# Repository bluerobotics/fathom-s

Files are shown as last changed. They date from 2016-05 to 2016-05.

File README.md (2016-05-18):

# Fathom-S

The Fathom Tether Boards are part of Blue Robotics' *Fathom Tether*. These boards provide interfaces and functionality for the communication methods used with the tether. With the Fathom tether, it is quick and easy to get up and running and interface with your ROV or other application.

The schematic and board layout are designed in EagleCAD.

Please see the [Blue Robotics Fathom-S Documentation Page](http://docs.bluerobotics.com/fathom-s/) for more information.

## License

The Fathom Serial Hardware Design is released under the MIT License.

## Revision History

0.0 - Under development. Not fully functional.

0.1 - Second prototype. Not fully functional.

0.2 - Third prototype. First beta release - works great.

0.3 - Rev5, incorporating big changes from beta tests.

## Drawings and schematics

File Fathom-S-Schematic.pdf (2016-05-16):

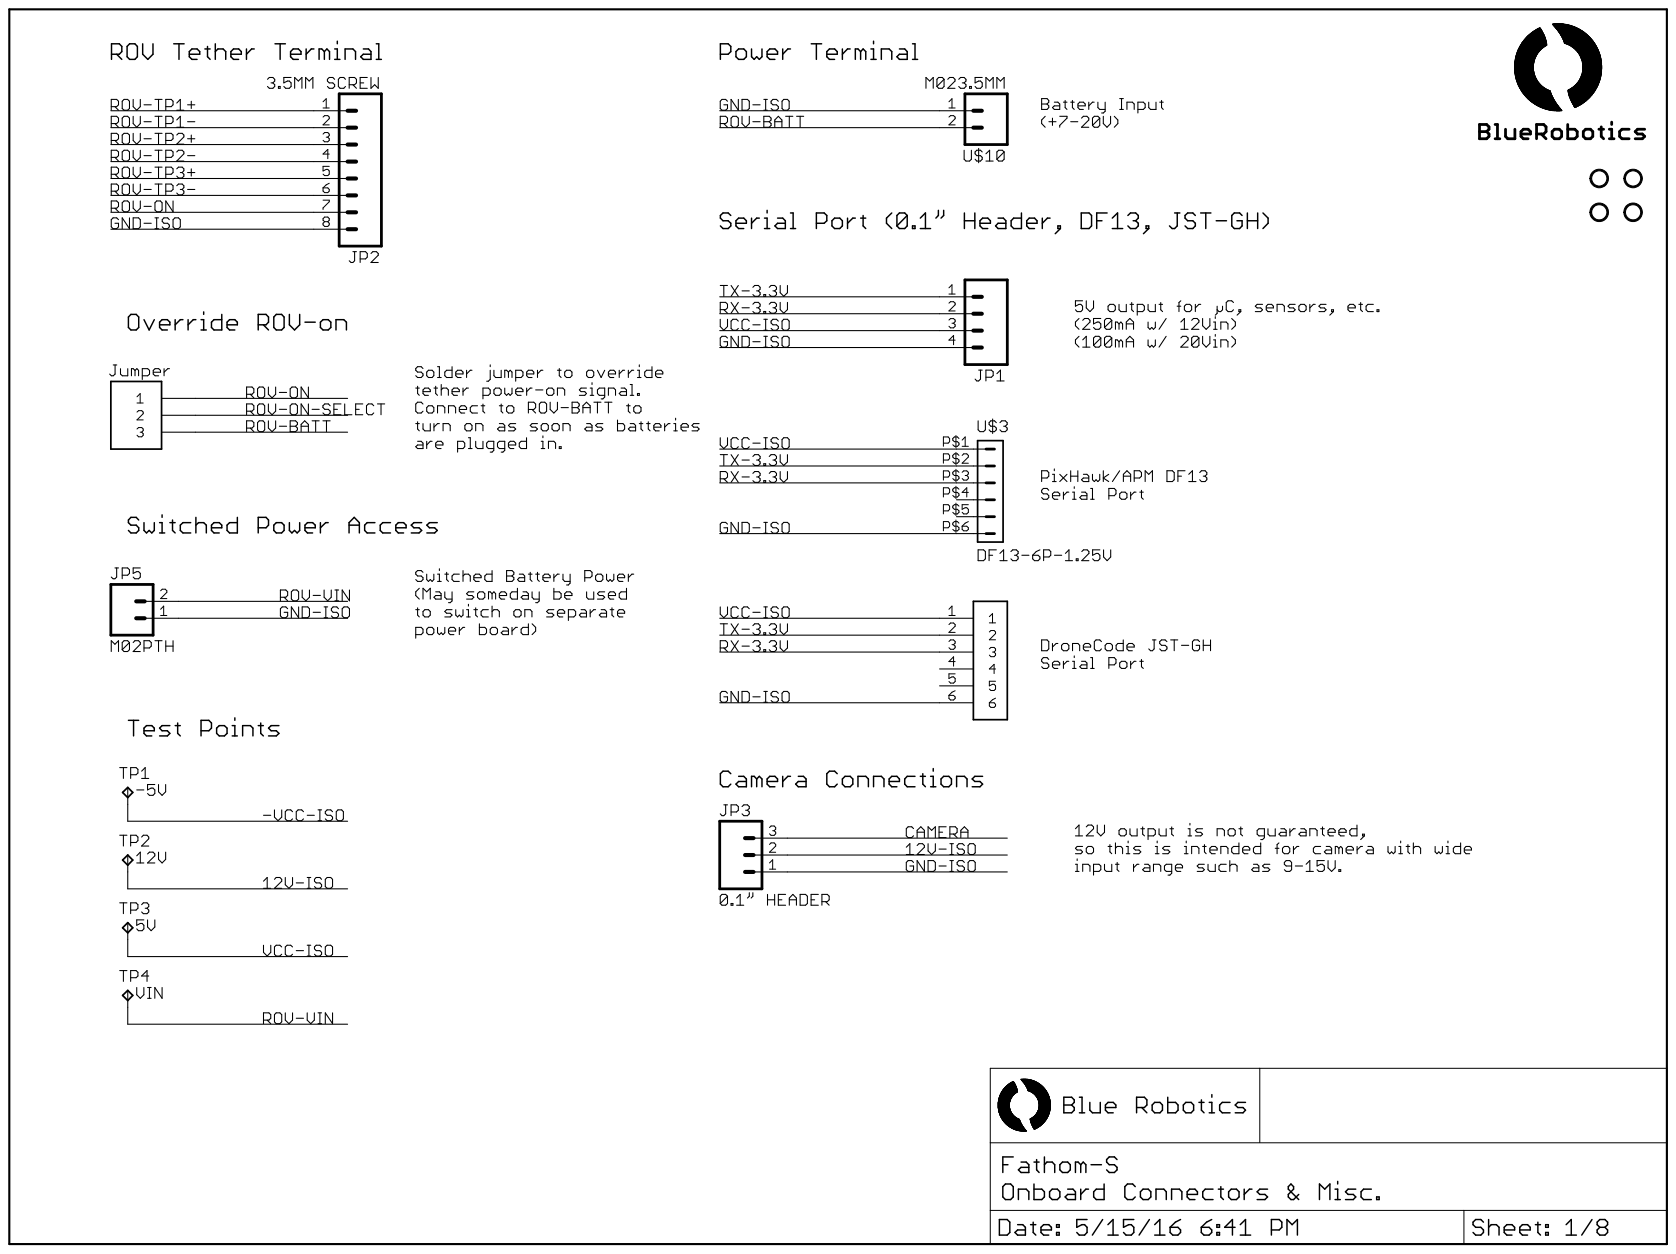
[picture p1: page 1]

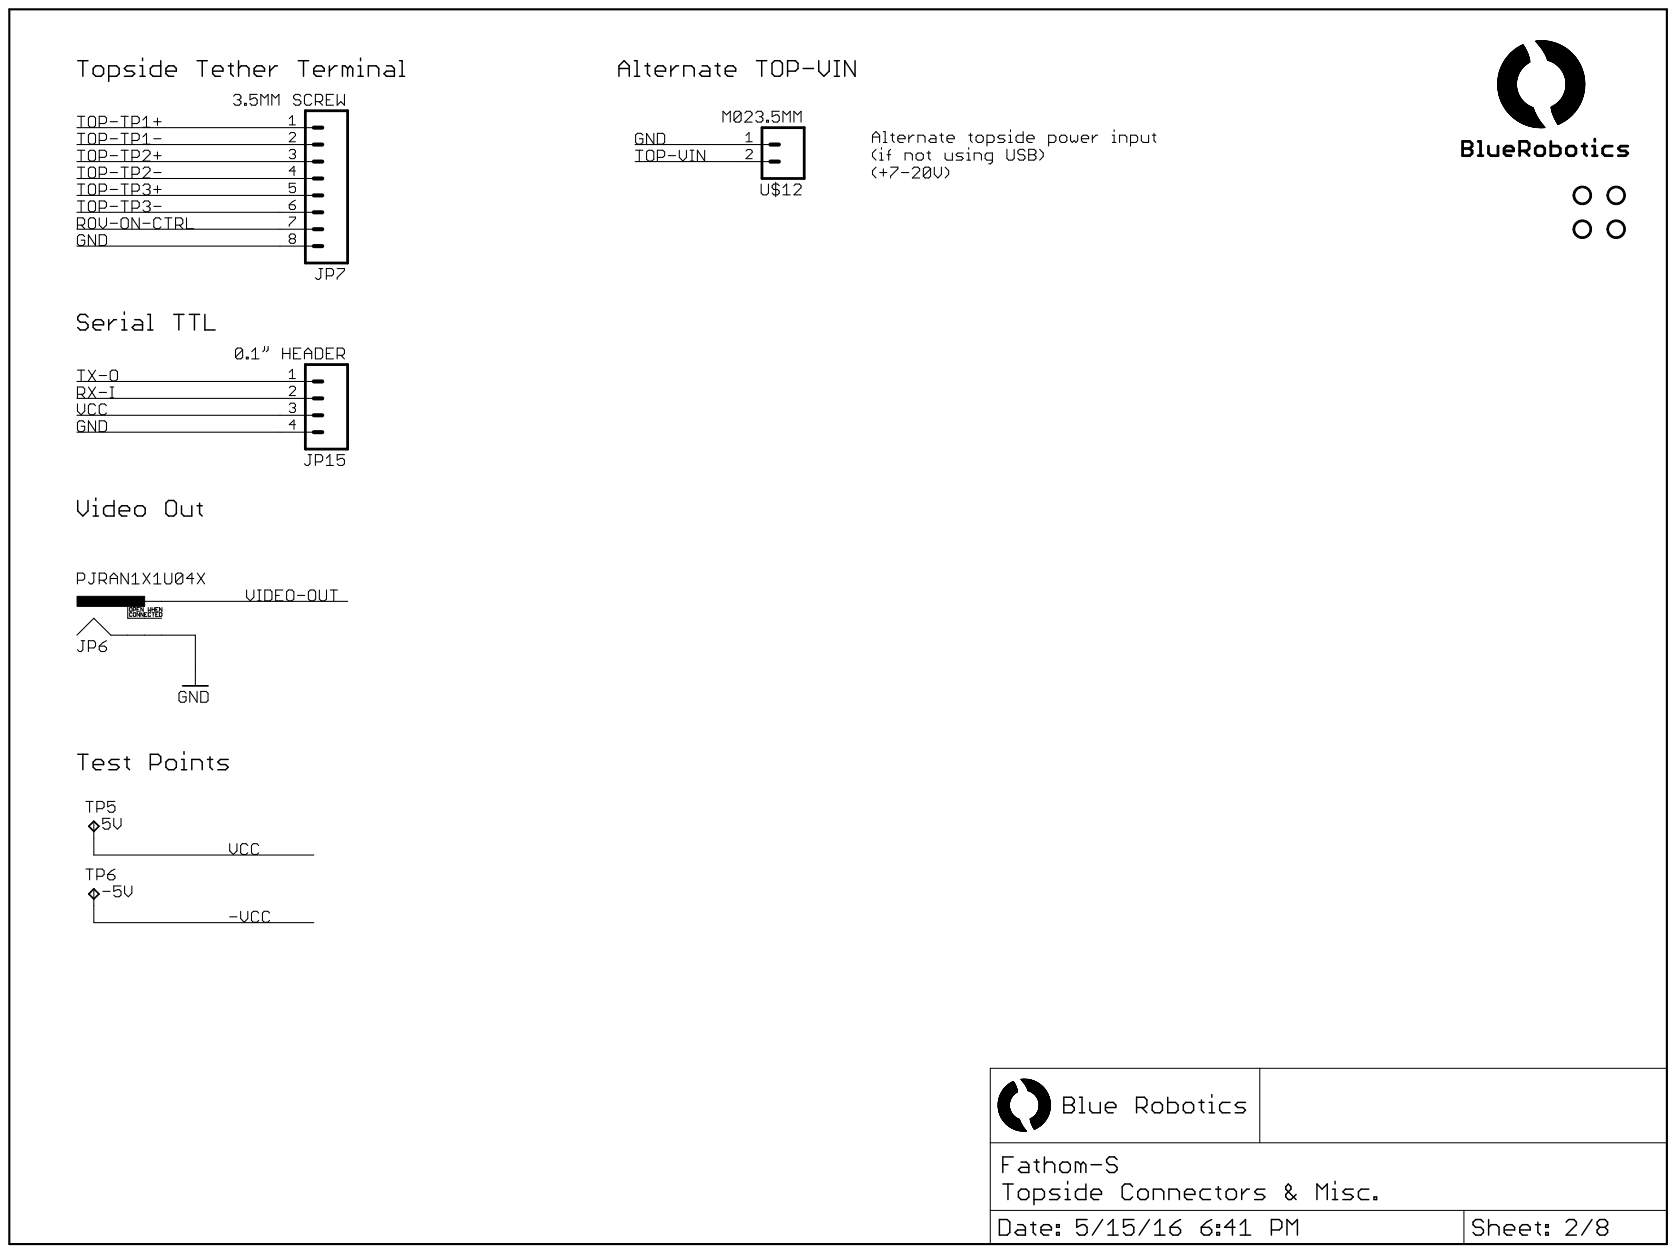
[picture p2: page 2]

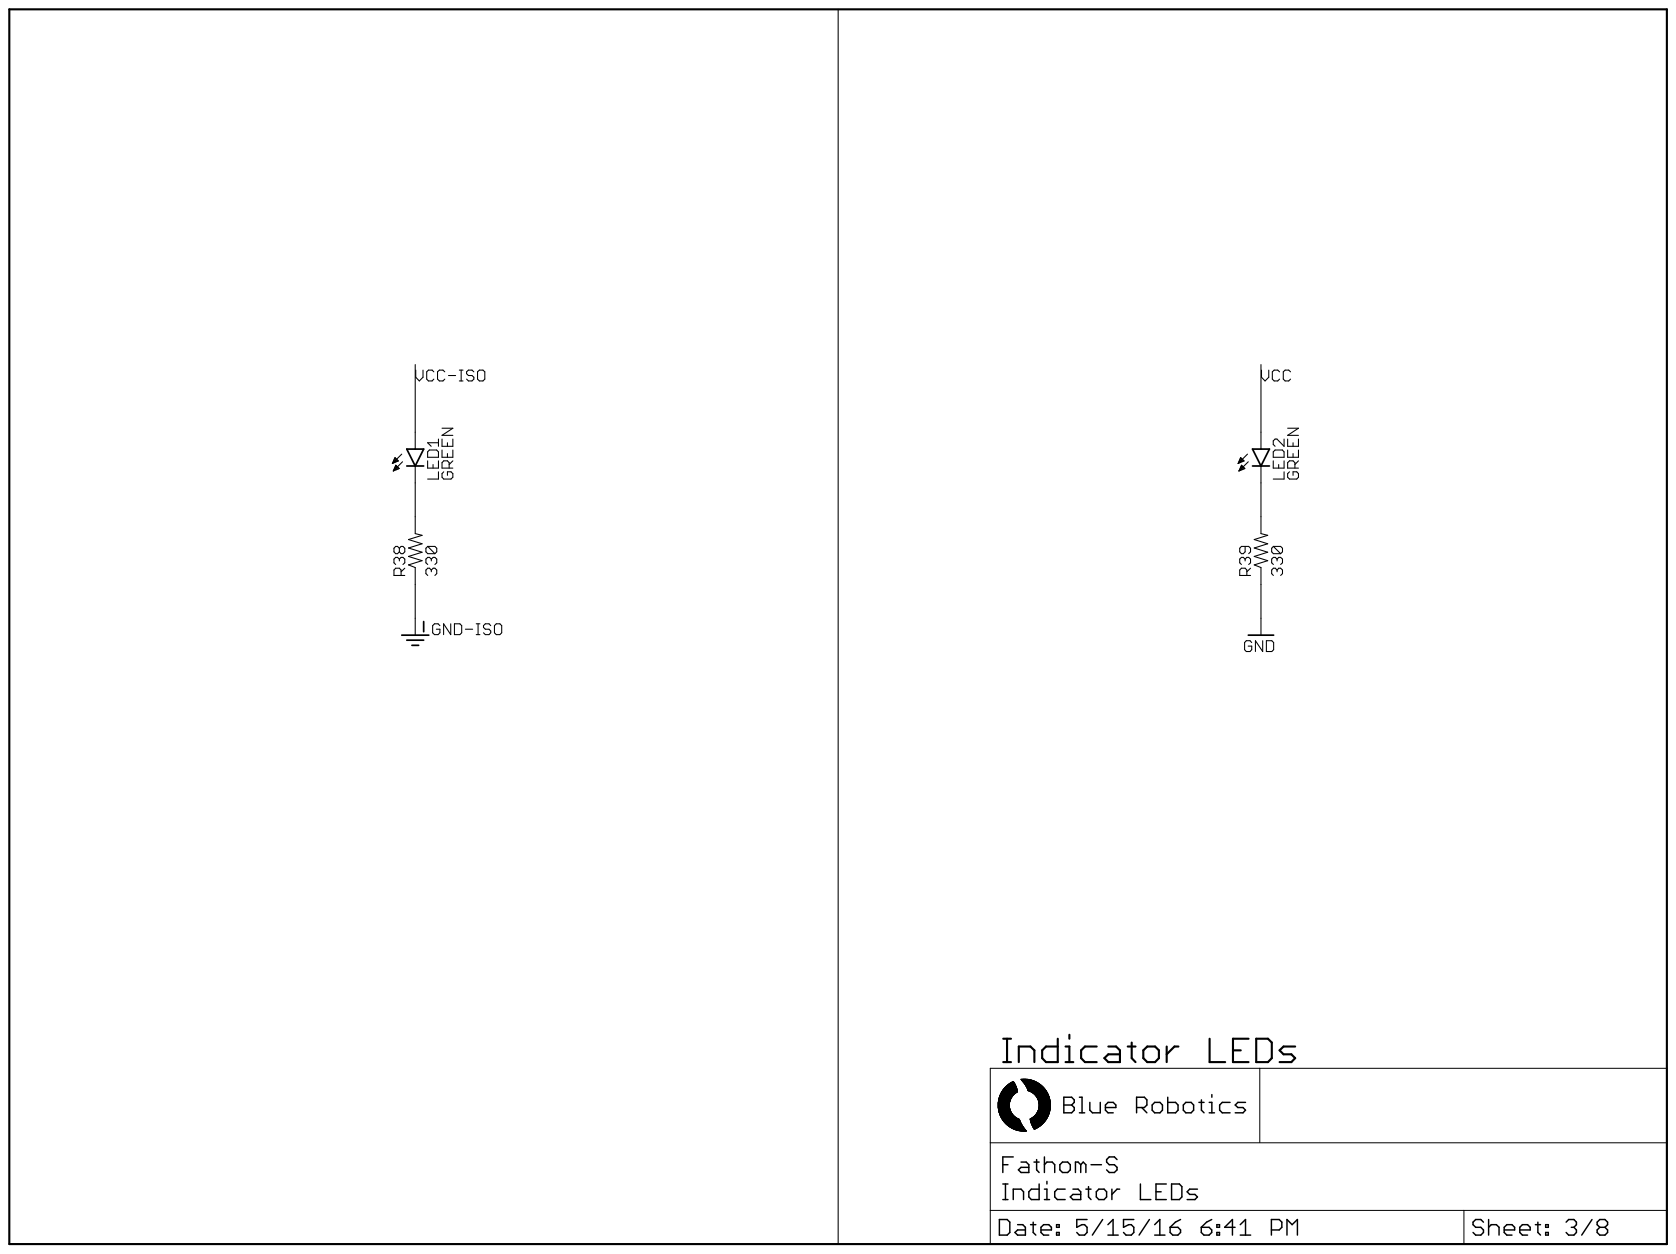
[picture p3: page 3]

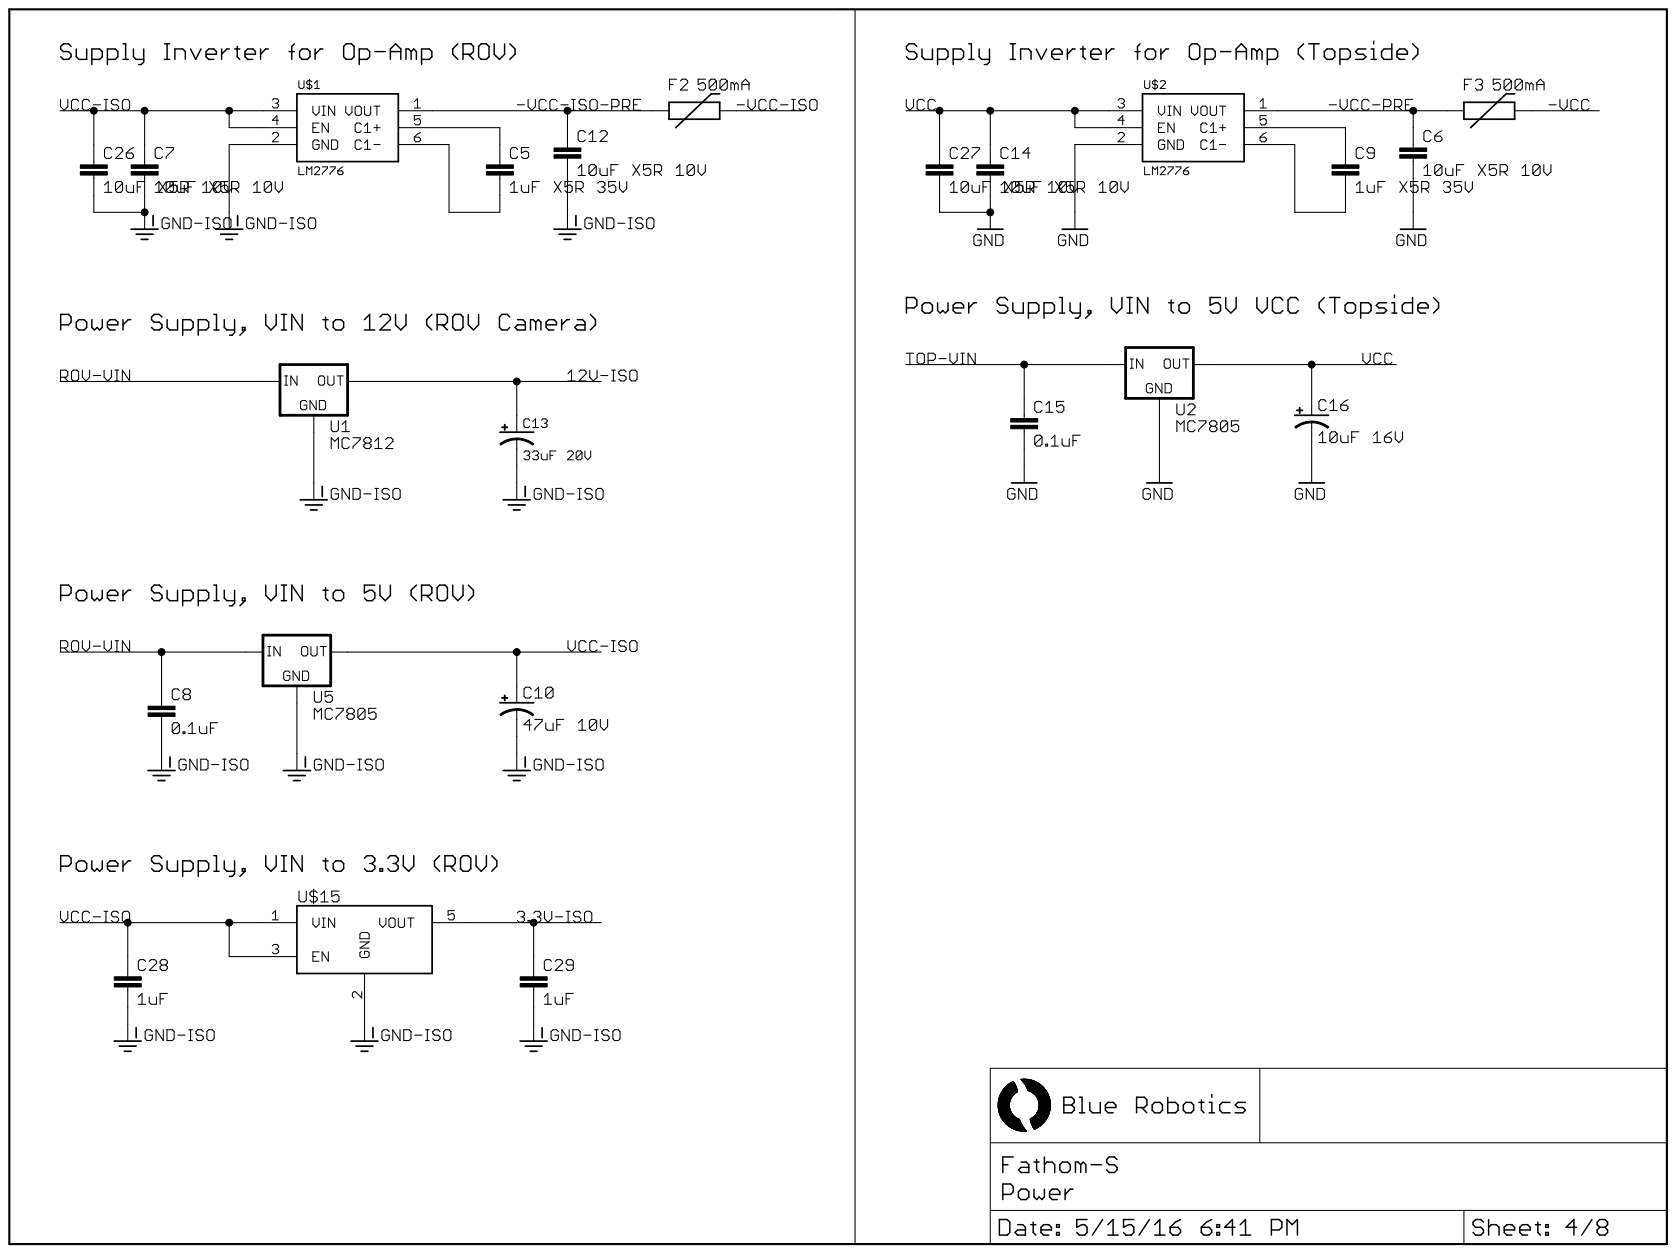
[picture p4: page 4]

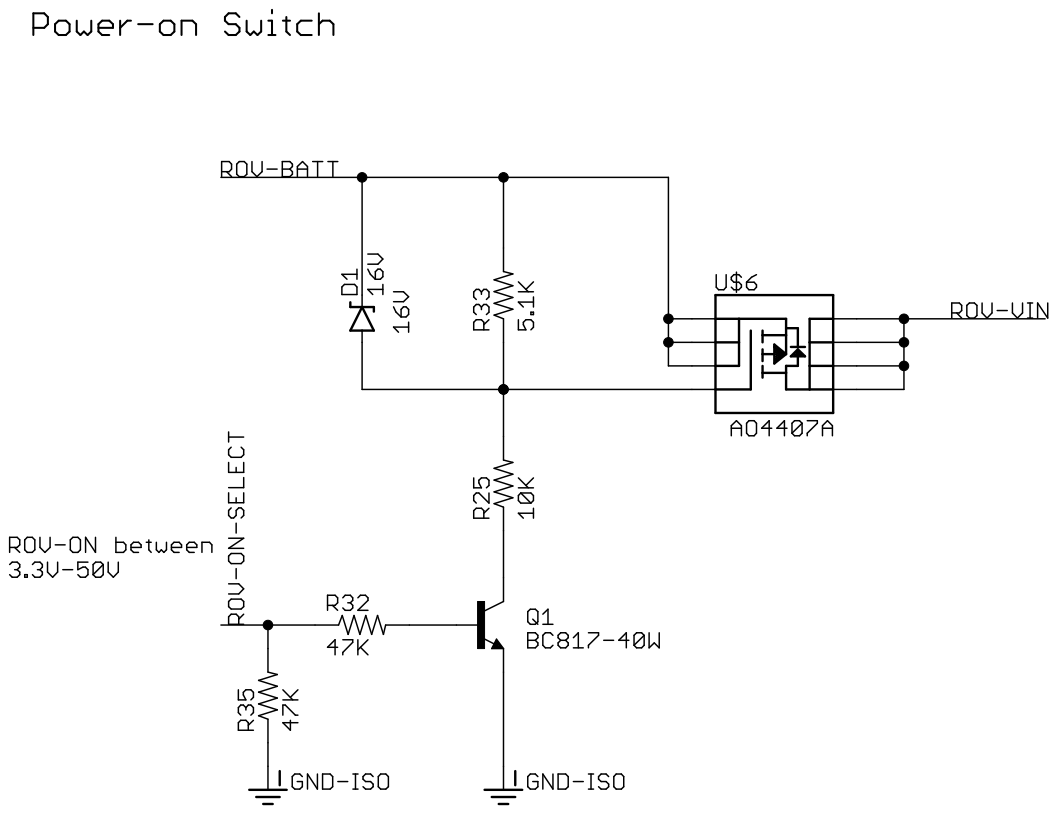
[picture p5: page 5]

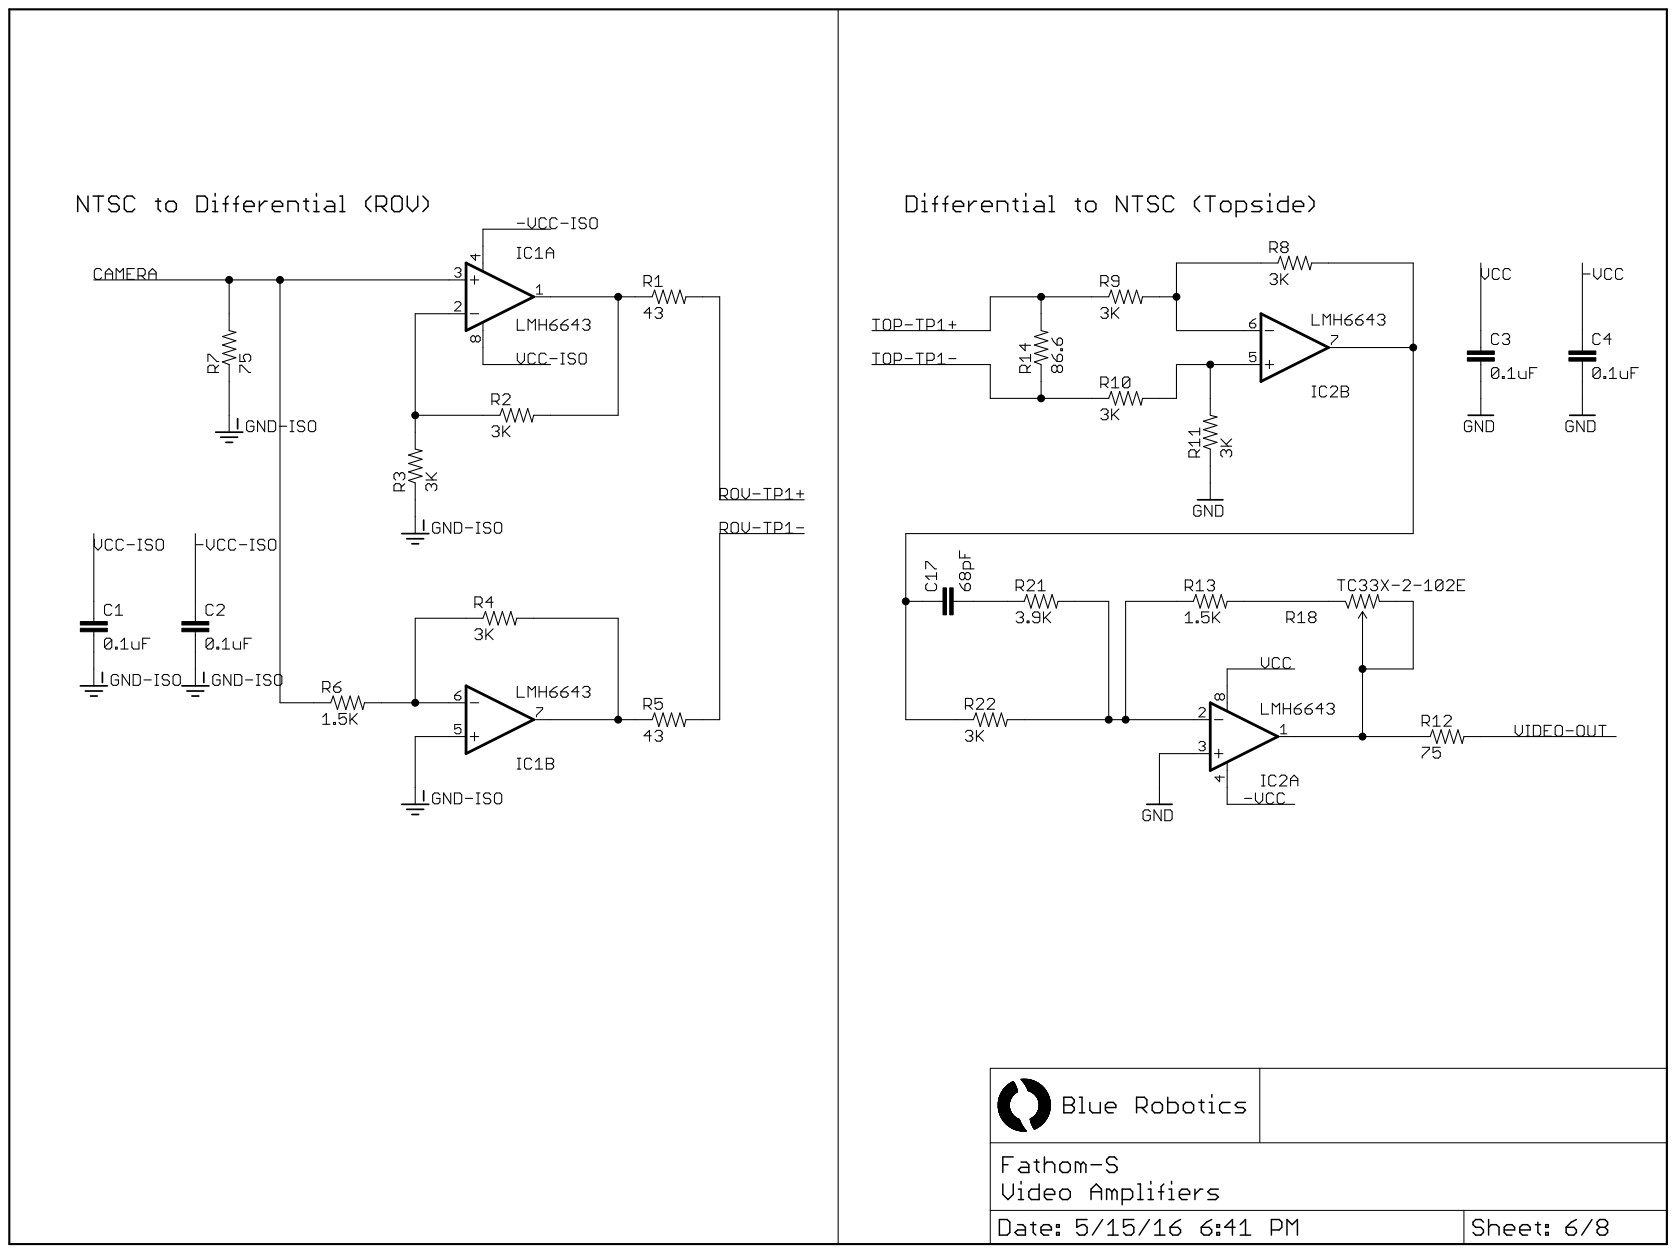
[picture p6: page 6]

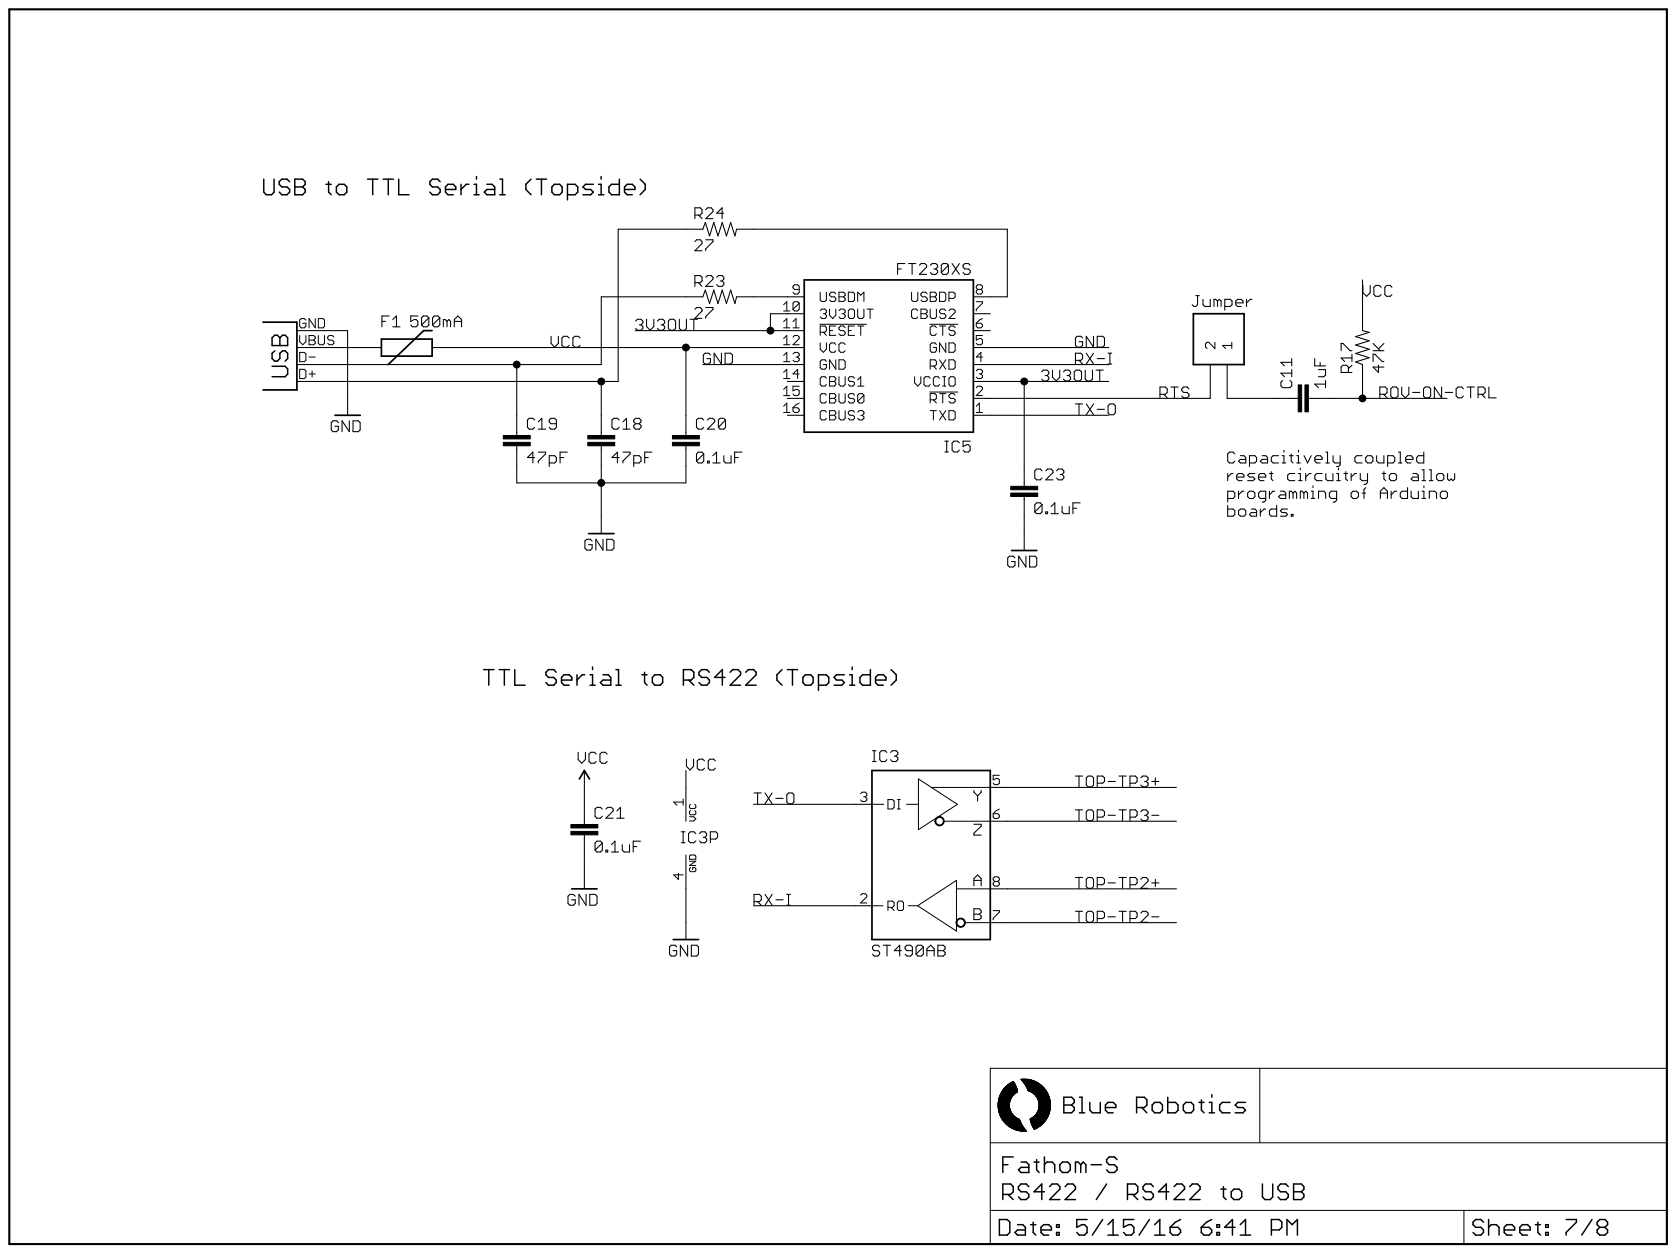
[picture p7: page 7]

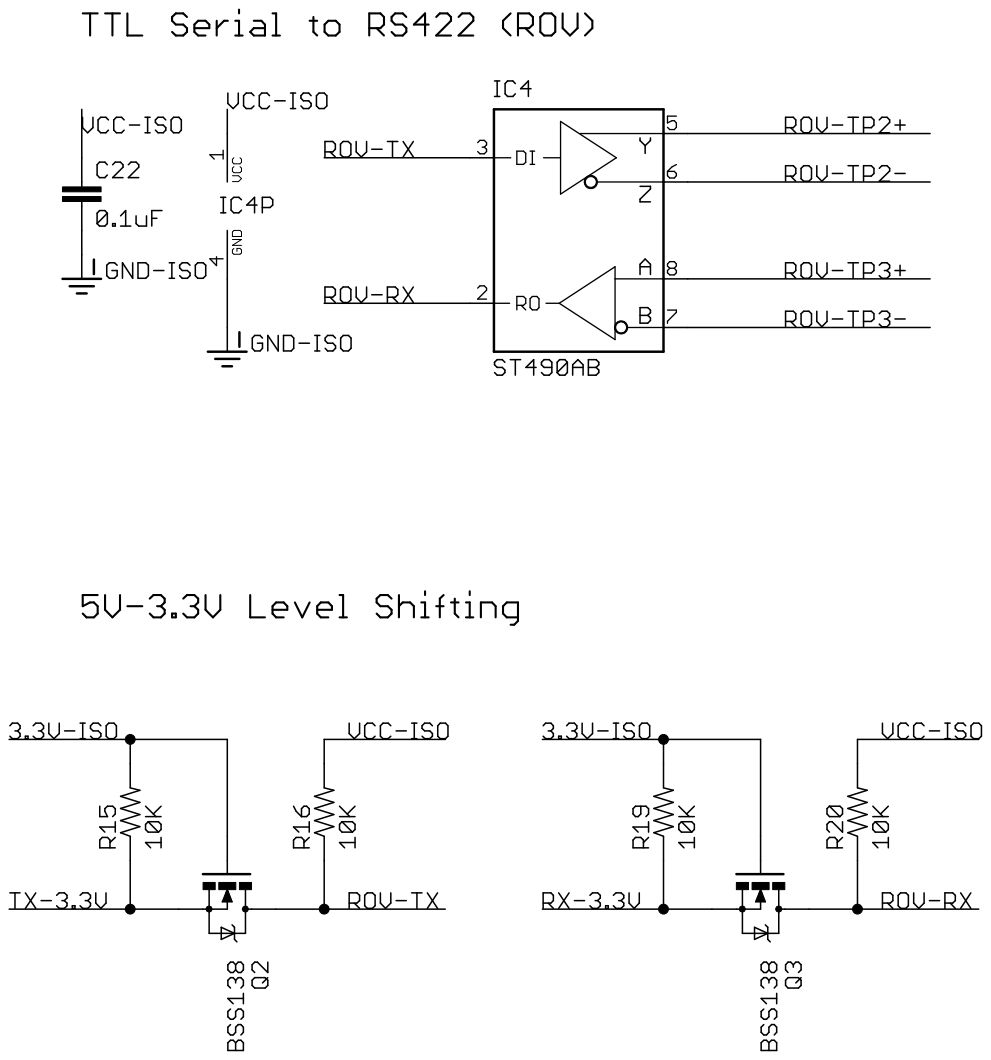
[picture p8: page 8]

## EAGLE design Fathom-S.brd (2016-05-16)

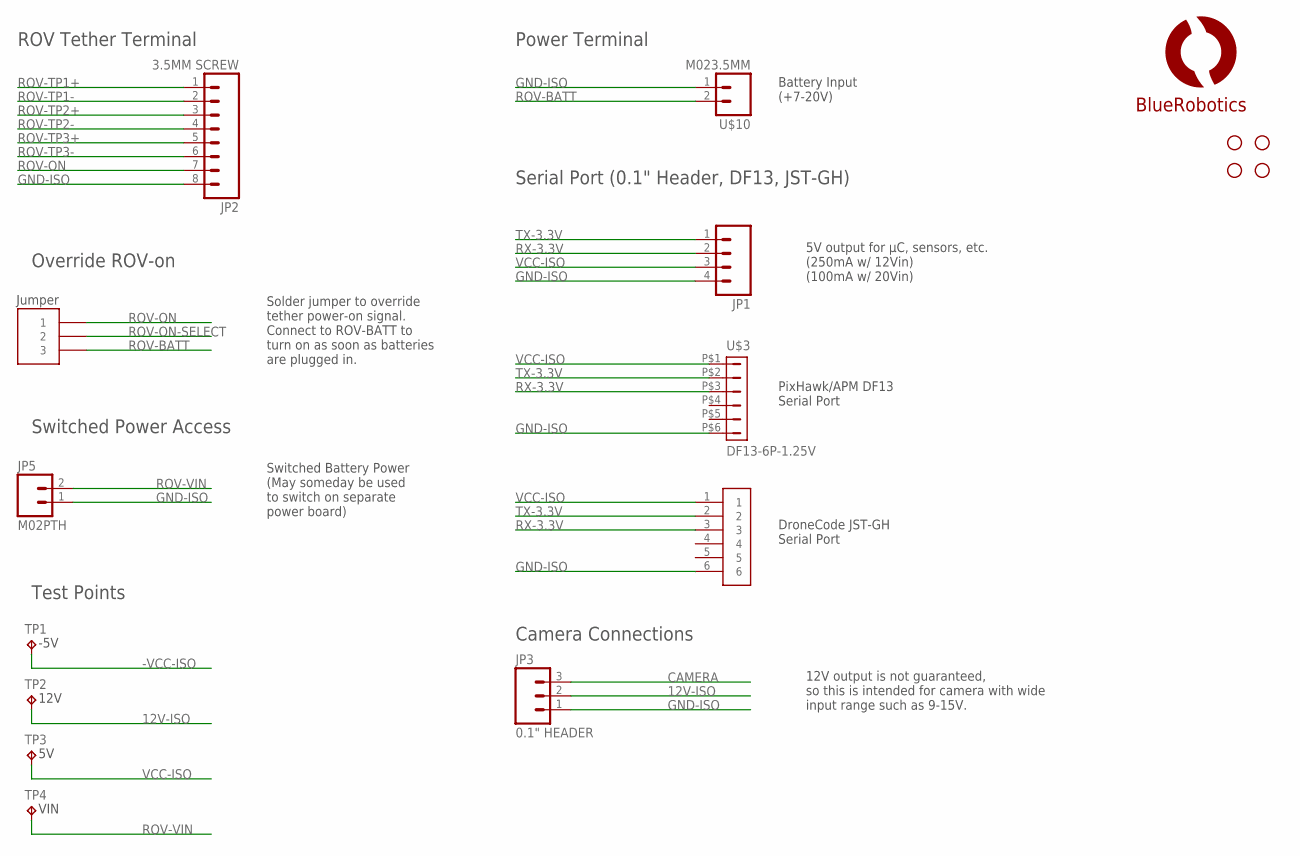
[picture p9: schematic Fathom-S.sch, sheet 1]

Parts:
JP1: M04PTH; 1X04
JP2: 3.5MM SCREW; SCREWTERMINAL-3.5MM-8
JP3: 0.1" HEADER; 1X03
JP5: M02PTH; 1X02
STANDOFF1, STANDOFF2, STANDOFF3, STANDOFF4: STAND-OFF
TP1: -5V; B1,27
TP2: 12V; B1,27
TP3: 5V; B1,27
TP4: VIN; B1,27
U$3: DF13-6P-1.25V; DF13C-6P-1.25V
U$4: LOGOFULL-M; BR-FULL-LOGO-MEDIUM
U$10: M023.5MM; SCREWTERMINAL-3.5MM-2
U$11: JST-GH-6TOP-ENTRY; JST-GH-TOP-6
U$13: HEADER-33MM; HEADER-2MM-3POS

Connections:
12V-ISO: JP3.2, TP2.TP; also elsewhere on the board
-VCC-ISO: TP1.TP; also elsewhere on the board
CAMERA: JP3.3; also elsewhere on the board
GND-ISO: JP1.4, JP2.8, JP3.1, JP5.1, U$3.P$6 (6), U$10.1, U$11.6; also elsewhere on the board
ROV-BATT: U$10.2, U$13.P$3 (3); also elsewhere on the board
ROV-ON: JP2.7, U$13.P$1 (1)
ROV-ON-SELECT: U$13.P$2 (2); also elsewhere on the board
ROV-TP1+: JP2.1; also elsewhere on the board
ROV-TP1-: JP2.2; also elsewhere on the board
ROV-TP2+: JP2.3; also elsewhere on the board
ROV-TP2-: JP2.4; also elsewhere on the board
ROV-TP3+: JP2.5; also elsewhere on the board
ROV-TP3-: JP2.6; also elsewhere on the board
ROV-VIN: JP5.2, TP4.TP; also elsewhere on the board
RX-3.3V: JP1.2, U$3.P$3 (3), U$11.3; also elsewhere on the board
TX-3.3V: JP1.1, U$3.P$2 (2), U$11.2; also elsewhere on the board
VCC-ISO: JP1.3, TP3.TP, U$3.P$1 (1), U$11.1; also elsewhere on the board

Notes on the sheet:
ROV Tether Terminal
Power Terminal
Camera Connections
Serial Port (0.1" Header, DF13, JST-GH)
Solder jumper to override tether power-on signal. Connect to ROV-BATT to turn on as soon as batteries are plugged in.
Override ROV-on
Battery Input (+7-20V)
5V output for µC, sensors, etc. (250mA w/ 12Vin) (100mA w/ 20Vin)
12V output is not guaranteed, so this is intended for camera with wide input range such as 9-15V.
Jumper
DroneCode JST-GH Serial Port
PixHawk/APM DF13 Serial Port
Switched Battery Power (May someday be used to switch on separate power board)
Switched Power Access
Test Points

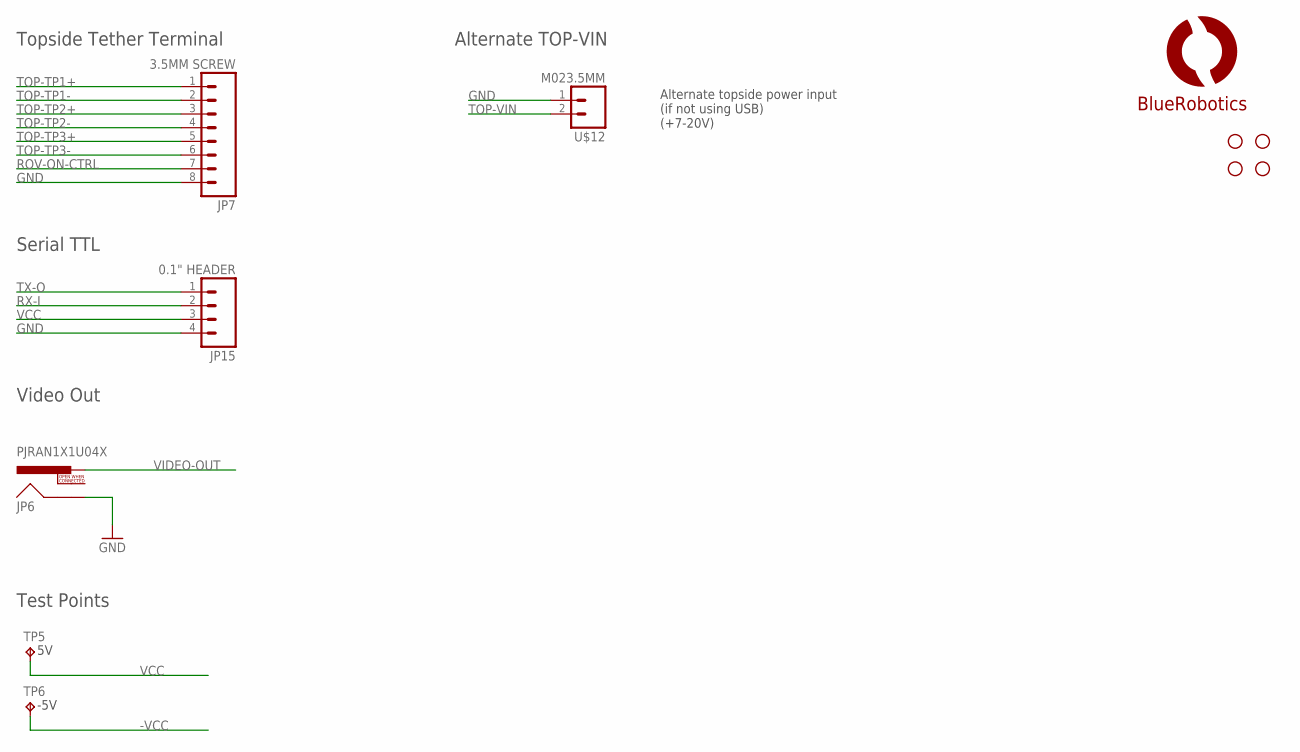
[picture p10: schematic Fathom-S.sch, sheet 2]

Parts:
JP6: PJRAN1X1U04X; RCA
JP7: 3.5MM SCREW; SCREWTERMINAL-3.5MM-8
JP15: 0.1" HEADER; 1X04
STANDOFF5, STANDOFF6, STANDOFF7, STANDOFF8: STAND-OFF
TP5: 5V; B1,27
TP6: -5V; B1,27
U$5: LOGOBR-LOGO-MS-COPPER; BR-LOGO-MEDIUM-SMALL-COPPER
U$12: M023.5MM; SCREWTERMINAL-3.5MM-2

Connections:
-VCC: TP6.TP; also elsewhere on the board
GND: JP6.SHELL, JP7.8, JP15.4, U$12.1; also elsewhere on the board
ROV-ON-CTRL: JP7.7; also elsewhere on the board
RX-I: JP15.2; also elsewhere on the board
TOP-TP1+: JP7.1; also elsewhere on the board
TOP-TP1-: JP7.2; also elsewhere on the board
TOP-TP2+: JP7.3; also elsewhere on the board
TOP-TP2-: JP7.4; also elsewhere on the board
TOP-TP3+: JP7.5; also elsewhere on the board
TOP-TP3-: JP7.6; also elsewhere on the board
TOP-VIN: U$12.2; also elsewhere on the board
TX-O: JP15.1; also elsewhere on the board
VCC: JP15.3, TP5.TP; also elsewhere on the board
VIDEO-OUT: JP6.PIN; also elsewhere on the board

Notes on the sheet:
Topside Tether Terminal
Alternate TOP-VIN
Video Out
Serial TTL
Alternate topside power input (if not using USB) (+7-20V)
Test Points

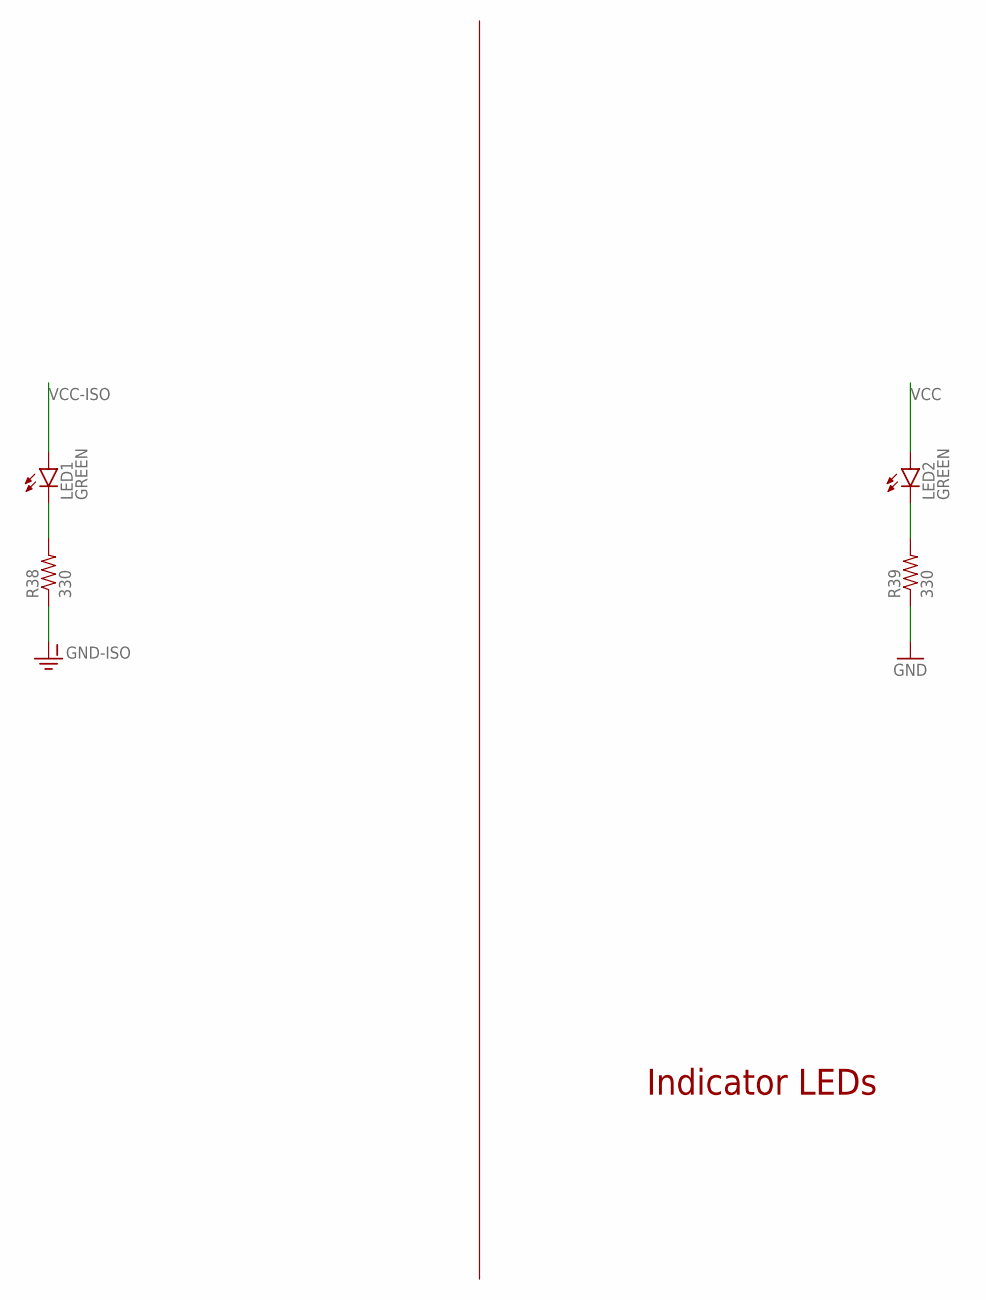
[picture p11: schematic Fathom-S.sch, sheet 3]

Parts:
LED1, LED2: GREEN; LED-0603
R38, R39: 330; 0603-RES

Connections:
GND: R39.1; also elsewhere on the board
GND-ISO: R38.1; also elsewhere on the board
unnamed: LED1.C, R38.2
unnamed: LED2.C, R39.2
VCC: LED2.A; also elsewhere on the board
VCC-ISO: LED1.A; also elsewhere on the board

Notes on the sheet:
Indicator LEDs

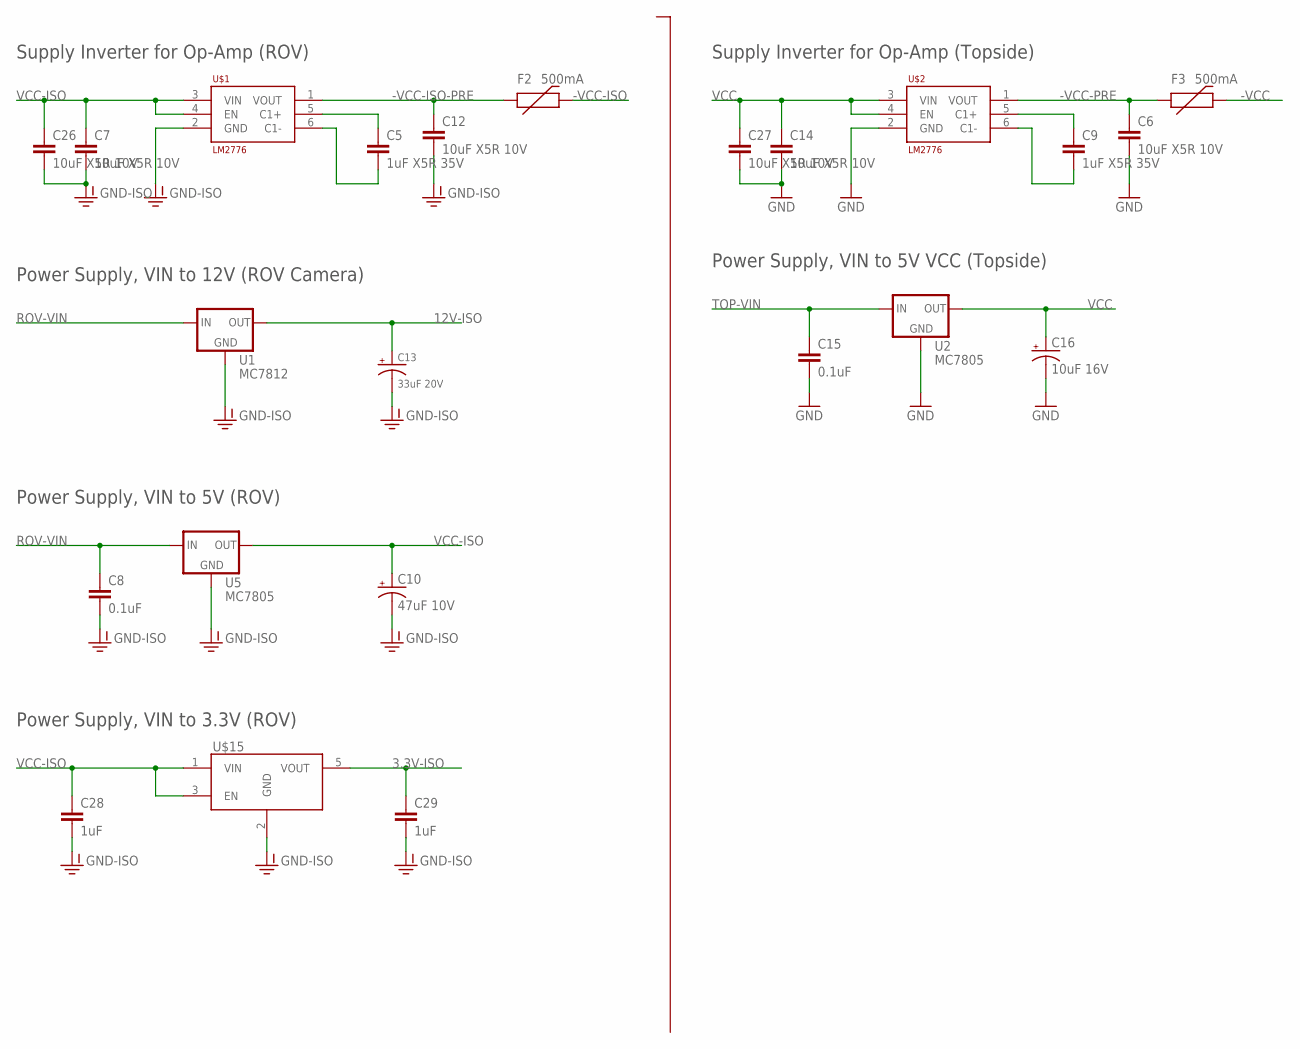
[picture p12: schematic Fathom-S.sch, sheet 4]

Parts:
C5, C9: 1uF X5R 35V; 0603-CAP
C6, C7, C12, C14, C26, C27: 10uF X5R 10V; 0805
C8, C15: 0.1uF; 0603-CAP
C10: 47uF 10V; EIA3528
C13: 33uF 20V; C2413
C16: 10uF 16V; EIA3216
C28, C29: 1uF; 0603-CAP
F2, F3: 500mA; 0603
U1: MC7812; DPAK
U2, U5: MC7805; DPAK
U$1, U$2: LM2776; SOT-23-6
U$15: VREG-MIC5365; SC70-5L

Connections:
3.3V-ISO: C29.1, U$15.5 (VOUT); also elsewhere on the board
12V-ISO: C13.+, U1.3 (OUT); also elsewhere on the board
-VCC: F3.2; also elsewhere on the board
-VCC-ISO: F2.2; also elsewhere on the board
-VCC-ISO-PRE: C12.1, F2.1, U$1.1 (VOUT)
-VCC-PRE: C6.1, F3.1, U$2.1 (VOUT)
GND: C6.2, C14.2, C15.2, C16.C (-), C27.2, U2.4 (GND), U$2.2 (GND); also elsewhere on the board
GND-ISO: C7.2, C8.2, C10.C (-), C12.2, C13.-, C26.2, C28.2, C29.2, U1.4 (GND), U5.4 (GND), U$1.2 (GND), U$15.2 (GND); also elsewhere on the board
unnamed: C9.1, U$2.5 (C1+)
unnamed: C9.2, U$2.6 (C1-)
unnamed: C5.1, U$1.5 (C1+)
unnamed: C5.2, U$1.6 (C1-)
ROV-VIN: C8.1, U1.1 (IN), U5.1 (IN); also elsewhere on the board
TOP-VIN: C15.1, U2.1 (IN); also elsewhere on the board
VCC: C14.1, C16.A (+), C27.1, U2.3 (OUT), U$2.3 (VIN), U$2.4 (EN); also elsewhere on the board
VCC-ISO: C7.1, C10.A (+), C26.1, C28.1, U5.3 (OUT), U$1.3 (VIN), U$1.4 (EN), U$15.1 (VIN), U$15.3 (EN); also elsewhere on the board

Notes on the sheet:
Supply Inverter for Op-Amp (ROV)
Supply Inverter for Op-Amp (Topside)
Power Supply, VIN to 12V (ROV Camera)
Power Supply, VIN to 5V (ROV)
Power Supply, VIN to 5V VCC (Topside)
Power Supply, VIN to 3.3V (ROV)

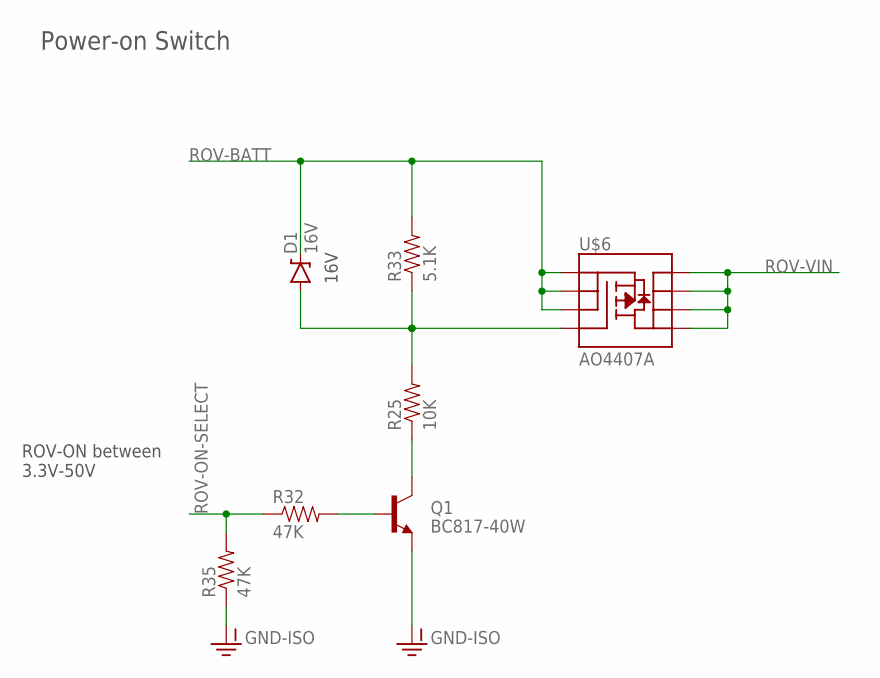
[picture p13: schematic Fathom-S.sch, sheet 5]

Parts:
D1: 16V; SOD-323
Q1: BC817-40W; SOT23
R25: 10K; 0603-RES
R32, R35: 47K; 0603-RES
R33: 5.1K; 0603-RES
U$6: AO4407A; SO08

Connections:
GND-ISO: Q1.2 (E), R35.1; also elsewhere on the board
unnamed: Q1.1 (B), R32.2
unnamed: D1.A, R25.2, R33.1, U$6.4 (G)
unnamed: Q1.3 (C), R25.1
ROV-BATT: D1.C, R33.2, U$6.1 (S), U$6.2 (S), U$6.3 (S); also elsewhere on the board
ROV-ON-SELECT: R32.1, R35.2; also elsewhere on the board
ROV-VIN: U$6.5 (D), U$6.6 (D), U$6.7 (D), U$6.8 (D); also elsewhere on the board

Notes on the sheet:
Power-on Switch
ROV-ON between 3.3V-50V
16V

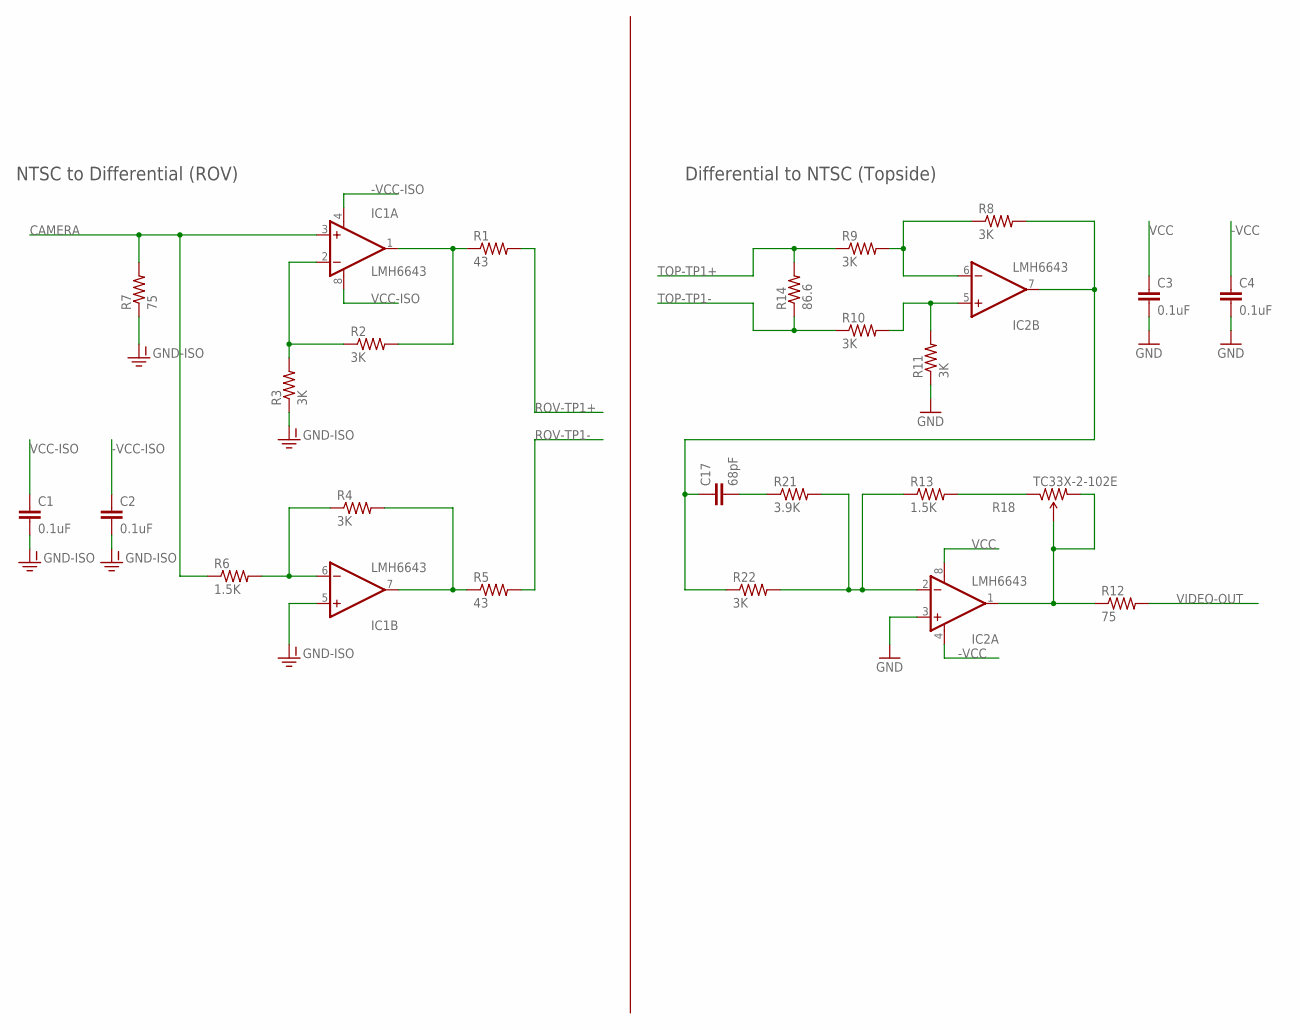
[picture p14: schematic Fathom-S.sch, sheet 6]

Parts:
C1, C2, C3, C4: 0.1uF; 0603-CAP
C17: 68pF; 0603-CAP
IC1, IC2: LMH6643; MSOP8
R1, R5: 43; 0603-RES
R2, R3, R4, R8, R9, R10, R11, R22: 3K; 0603-RES
R6, R13: 1.5K; 0603-RES
R7, R12: 75; 0603-RES
R14: 86.6; 0603-RES
R18: TC33X-2-102E; TRIMPOT_TC33
R21: 3.9K; 0603-RES

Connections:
-VCC: C4.1, IC2.4 (V-); also elsewhere on the board
-VCC-ISO: C2.1, IC1.4 (V-); also elsewhere on the board
CAMERA: IC1.3 (+IN), R6.1, R7.2; also elsewhere on the board
GND: C3.2, C4.2, IC2.3 (+IN), R11.1; also elsewhere on the board
GND-ISO: C1.2, C2.2, IC1.5 (+IN), R3.1, R7.1; also elsewhere on the board
unnamed: IC1.1 (OUT), R1.1, R2.2
unnamed: IC1.7 (OUT), R4.2, R5.1
unnamed: IC1.2 (-IN), R2.1, R3.2
unnamed: IC1.6 (-IN), R4.1, R6.2
unnamed: IC2.5 (+IN), R10.2, R11.2
unnamed: IC2.6 (-IN), R8.1, R9.2
unnamed: R13.2, R18.1 (CCW)
unnamed: C17.1, IC2.7 (OUT), R8.2, R22.1
unnamed: IC2.2 (-IN), R13.1, R21.2, R22.2
unnamed: C17.2, R21.1
unnamed: IC2.1 (OUT), R12.1, R18.2 (WIPER), R18.3 (CW)
ROV-TP1+: R1.2; also elsewhere on the board
ROV-TP1-: R5.2; also elsewhere on the board
TOP-TP1+: R9.1, R14.2; also elsewhere on the board
TOP-TP1-: R10.1, R14.1; also elsewhere on the board
VCC: C3.1, IC2.8 (V+); also elsewhere on the board
VCC-ISO: C1.1, IC1.8 (V+); also elsewhere on the board
VIDEO-OUT: R12.2; also elsewhere on the board

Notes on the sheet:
NTSC to Differential (ROV)
Differential to NTSC (Topside)

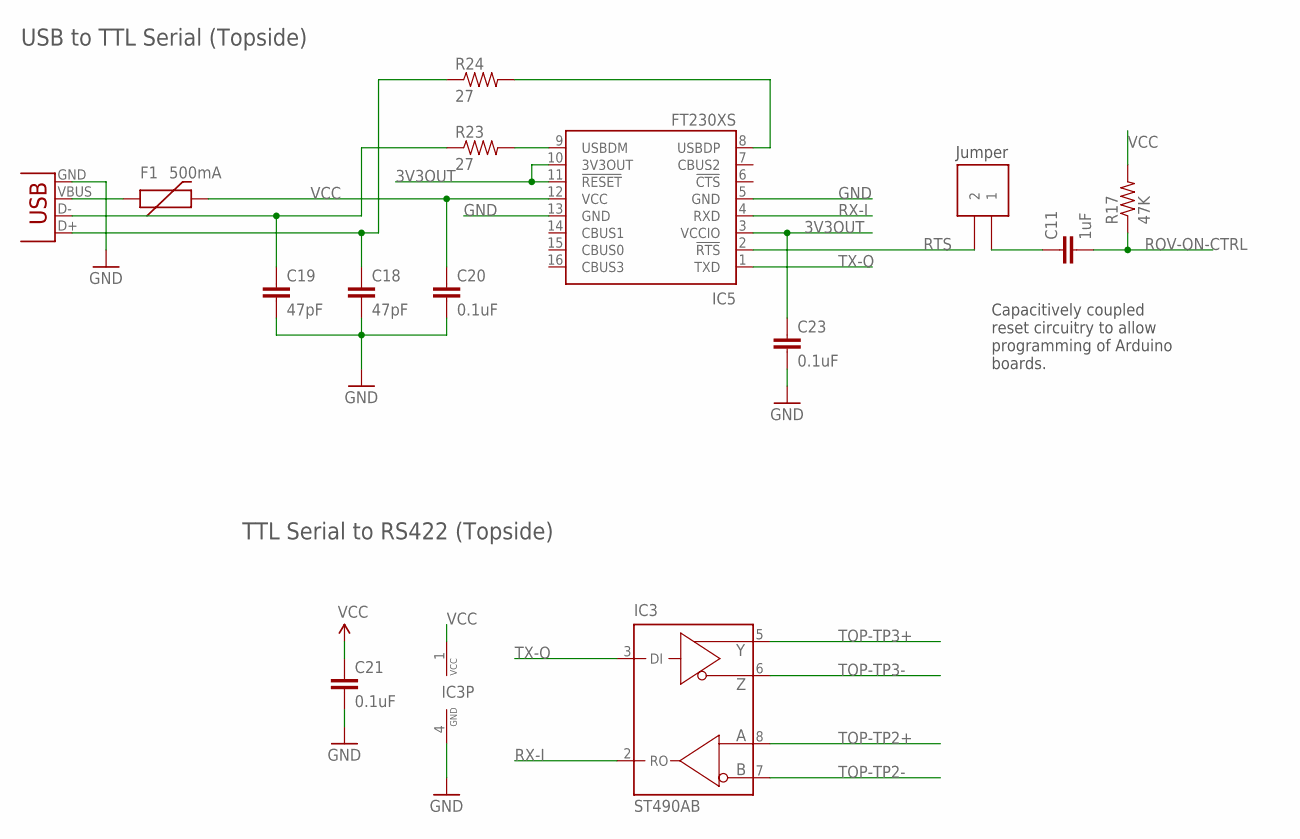
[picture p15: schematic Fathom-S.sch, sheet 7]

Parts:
C11: 1uF; 0603-CAP
C18, C19: 47pF; 0603-CAP
C20, C21, C23: 0.1uF; 0603-CAP
F1: 500mA; 0603
IC3: ST490AB; SO08
IC5: FT230XS; SSOP16
R17: 47K; 0603-RES
R23, R24: 27; 0603-RES
U$16: HEADER-22MM; HEADER-2MM-2POS
X2: USBSMD; USB-MINIB

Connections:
3V3OUT: C23.1, IC5.3 (VCCIO), IC5.10 (3V3OUT), IC5.11 (!RESET)
GND: C18.2, C19.2, C20.2, C21.2, C23.2, IC3.4 (GND), IC5.5 (GND), IC5.13 (GND), X2.GND; also elsewhere on the board
unnamed: C11.1, U$16.P$1 (1)
unnamed: C19.1, R23.1, X2.D-
unnamed: C18.1, R24.1, X2.D+
unnamed: F1.1, X2.VBUS
unnamed: IC5.8 (USBDP), R24.2
unnamed: IC5.9 (USBDM), R23.2
ROV-ON-CTRL: C11.2, R17.1; also elsewhere on the board
RTS: IC5.2 (!RTS), U$16.P$2 (2)
RX-I: IC3.2 (RO), IC5.4 (RXD); also elsewhere on the board
TOP-TP2+: IC3.8 (A); also elsewhere on the board
TOP-TP2-: IC3.7 (B); also elsewhere on the board
TOP-TP3+: IC3.5 (Y); also elsewhere on the board
TOP-TP3-: IC3.6 (Z); also elsewhere on the board
TX-O: IC3.3 (DI), IC5.1 (TXD); also elsewhere on the board
VCC: C20.1, C21.1, F1.2, IC3.1 (VCC), IC5.12 (VCC), R17.2; also elsewhere on the board

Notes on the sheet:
USB to TTL Serial (Topside)
TTL Serial to RS422 (Topside)
Capacitively coupled reset circuitry to allow programming of Arduino boards.
Jumper

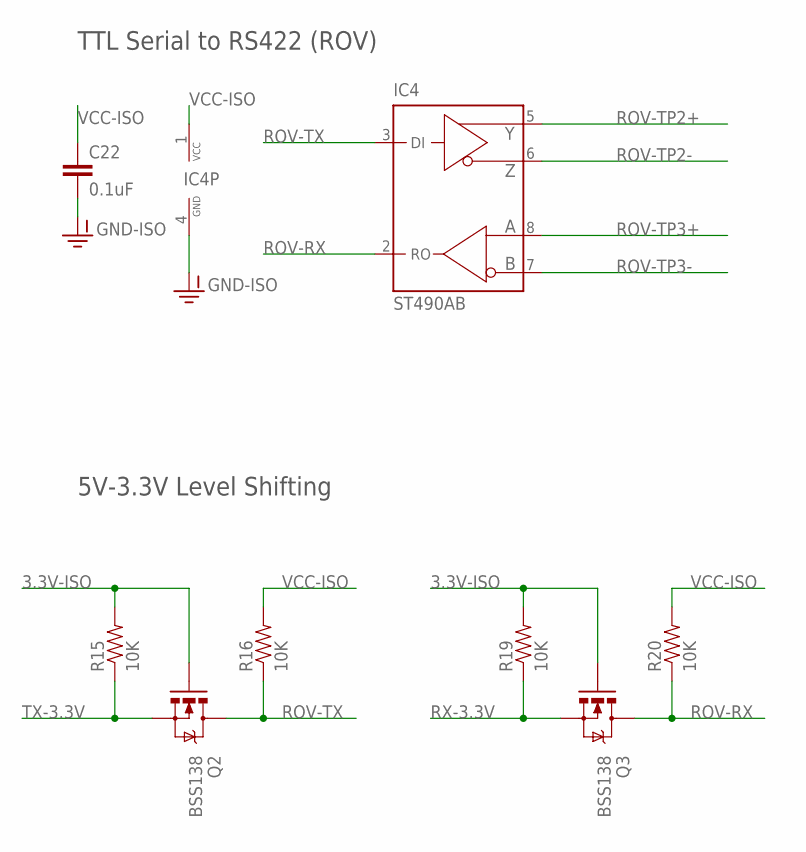
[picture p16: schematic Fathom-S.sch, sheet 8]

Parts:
C22: 0.1uF; 0603-CAP
IC4: ST490AB; SO08
Q2, Q3: BSS138; SOT23
R15, R16, R19, R20: 10K; 0603-RES

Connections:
3.3V-ISO: Q2.1 (G), Q3.1 (G), R15.2, R19.2; also elsewhere on the board
GND-ISO: C22.2, IC4.4 (GND); also elsewhere on the board
ROV-RX: IC4.2 (RO), Q3.3 (D), R20.1
ROV-TP2+: IC4.5 (Y); also elsewhere on the board
ROV-TP2-: IC4.6 (Z); also elsewhere on the board
ROV-TP3+: IC4.8 (A); also elsewhere on the board
ROV-TP3-: IC4.7 (B); also elsewhere on the board
ROV-TX: IC4.3 (DI), Q2.3 (D), R16.1
RX-3.3V: Q3.2 (S), R19.1; also elsewhere on the board
TX-3.3V: Q2.2 (S), R15.1; also elsewhere on the board
VCC-ISO: C22.1, IC4.1 (VCC), R16.2, R20.2; also elsewhere on the board

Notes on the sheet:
TTL Serial to RS422 (ROV)
5V-3.3V Level Shifting

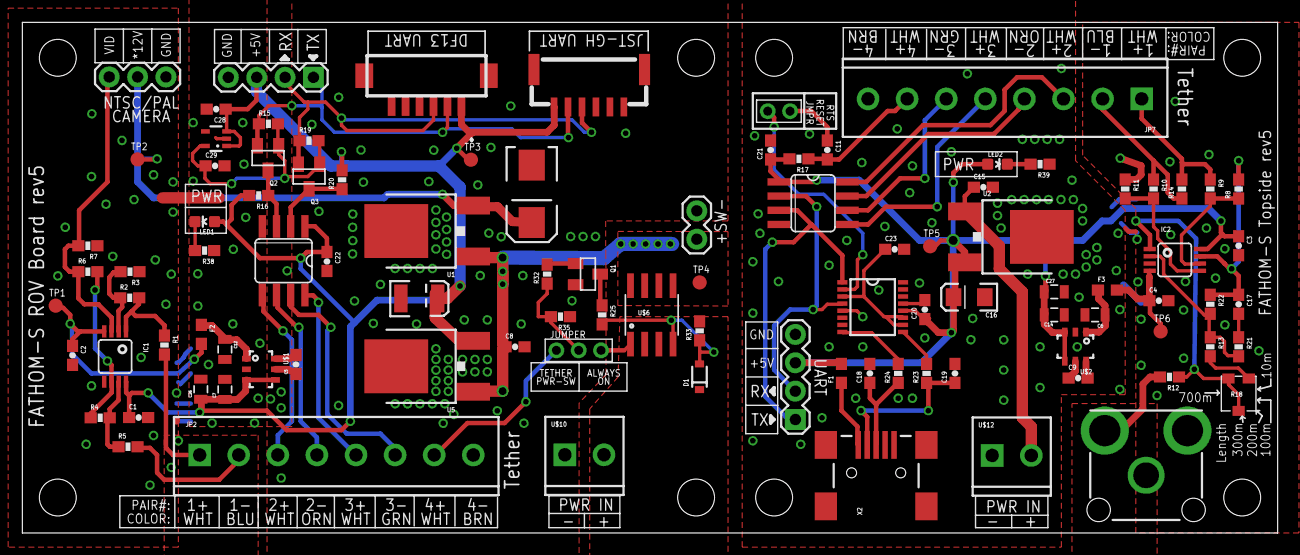
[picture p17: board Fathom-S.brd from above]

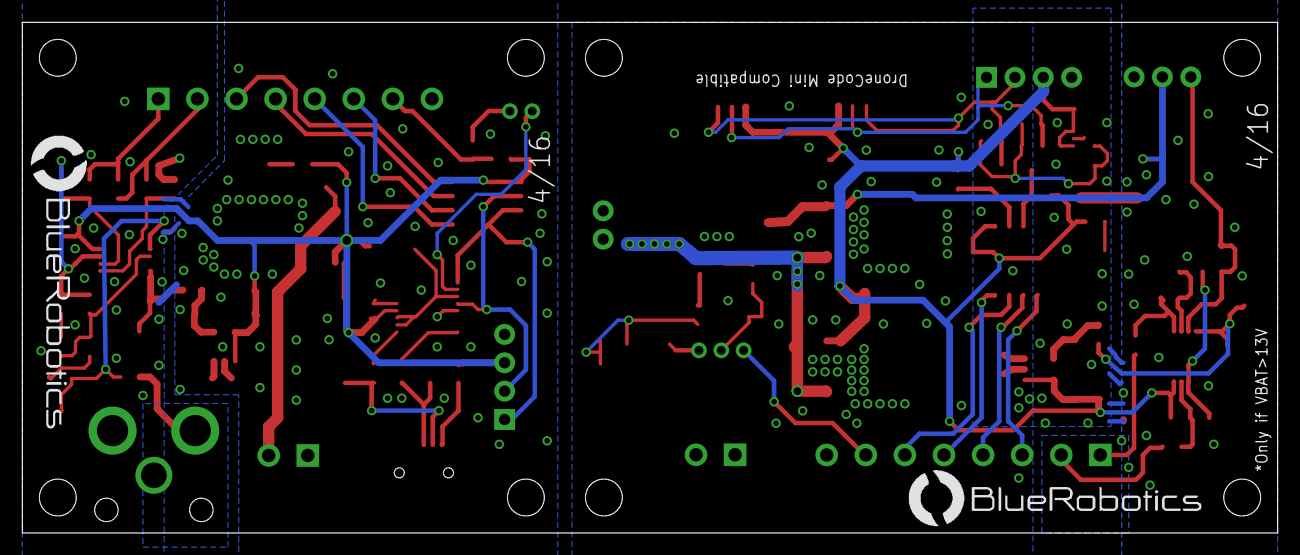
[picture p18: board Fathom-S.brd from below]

Board: 2 copper layers, 112.4 x 45.7 mm, 110 parts (2 on the bottom side), 64 nets.

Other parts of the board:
U$7: LOGOFULL-M; BR-FULL-LOGO-MEDIUM
U$9: LOGOBR-LOGO-MS; BR-LOGO-MEDIUM-SMALL-COPPER

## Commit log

2015-10-11 Initial commit, already pretty fully designed, but not yet produced or tested.
    [Fathom-Serial.brd, Fathom-Serial.sch]
2015-10-12 Increased termination resistor size appropriately for RS485. Hopefully we can get by without using these eventually.
    [Fathom-Serial.brd, Fathom-Serial.sch]
2015-10-12 Updated tether ribbon header size and pinout.
    [Fathom-Serial.brd, Fathom-Serial.sch]
2015-10-12 Adjusted silkscreen text.
    [Fathom-Serial.brd]
2015-10-18 Minor update to readme.
    [Fathom-Serial.brd]
2015-11-01 Lots of changes based on testing of first prototype. Fixed regulators, removed RX/TX leds, added RTS reset, changed negative supply capacitors.
    [Fathom-Serial.brd, Fathom-Serial.sch]
2015-11-02 Updated schematic frames and changed references from 485 to 422.
    [Fathom-Serial.sch]
2015-11-02 Changed file names.
    [Fathom-S.brd, Fathom-S.sch]
2015-11-05 Changed lm2776 components to match datasheet and hopefully fix our issues.
    [Fathom-S.brd, Fathom-S.sch]
2015-11-05 Layout 'typos' fixed.
    [Fathom-S.brd, Fathom-S.sch]
2015-11-19 Redid the layout for the video amplifiers and supply inverters to help fix recent issues. There is now an analog ground plane. LM2776 are laid out almost identical to the eval board.
    [Fathom-S.brd, Fathom-S.sch]
2015-11-19 Fixed a few minor ground issues.
    [Fathom-S.brd]
2015-11-20 Fixed a bunch of routing issues, added more ground vias, changed ground planes a bit.
    [Fathom-S.brd]
2015-11-21 Changed the op-amp package because the MSOPs are much cheaper for some reason.
    [Fathom-S.brd, Fathom-S.sch]
2015-11-21 Minor changes to readme and silkscreen.
    [Fathom-S.brd, Fathom-S.sch]
2015-11-23 Yet more layout changes and added ferrite beads to the -5V outputs for better noise rejection.
    [Fathom-S.brd, Fathom-S.sch]
2015-11-24 Fixed a few more layout issues and connected the pot wiper to open end for safety.
    [Fathom-S.brd, Fathom-S.sch]
2015-11-24 Moved components slightly to move pot up.
    [Fathom-S.brd]
2015-11-24 Minor fix.
    [Fathom-S.brd]
2015-11-24 Fixed an unnecessarily long 12V trace.
    [Fathom-S.brd]
2015-12-16 Removed soldermask from vias.
    [Fathom-S.brd]
2015-12-16 Adding APM/Pixhawk adapter. This has level shifters and stuff, but apparently the Pixhawk serial port is 5V tolerant so I will be removing them and making it simple.
    [APM-PX-Adapter.brd, APM-PX-Adapter.sch]
2015-12-16 Removed level shifting and switch to all through hole components. Ordering a prototype.
    [APM-PX-Adapter.brd, APM-PX-Adapter.sch]
2015-12-18 Change resistor value to fix RTS reset and added more thermal vias for regulators.
    [Fathom-S.brd, Fathom-S.sch]
2015-12-23 Changed jumpers from solder to headers. This rev4 and the beta boards will be ordered from this commit.
    [Fathom-S.brd, Fathom-S.sch]
2016-04-16 Updates to adapter board.
    [APM-PX-Adapter.brd, APM-PX-Adapter.sch]
2016-04-16 Massive revision to simplify and make easier to use. Added DroneCode connectors, removed excessive stuff, and removed power switching.
    [Fathom-S.brd, Fathom-S.sch]
2016-04-18 Change 12V output capacitor size.
    [Fathom-S.brd, Fathom-S.sch]
2016-04-20 Switch to FET based level shifting for 5V tolerance.
    [Fathom-S.brd, Fathom-S.sch]
2016-04-25 Further updates to Rev5. First production run.
    [Fathom-S.brd, Fathom-S.sch]
2016-05-16 Updated files before release.
    [Fathom-S.brd, Fathom-S.sch]
2016-05-16 Remove irrelevant adapter boards.
    [APM-PX-Adapter.brd, APM-PX-Adapter.sch]

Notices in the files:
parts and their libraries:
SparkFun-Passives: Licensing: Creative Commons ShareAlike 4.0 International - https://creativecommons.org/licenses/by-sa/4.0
